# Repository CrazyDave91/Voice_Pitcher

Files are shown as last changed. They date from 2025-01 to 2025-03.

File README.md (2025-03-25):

# Voice Pitcher

This Project implements an Arduino Uno based voice pitcher with mic input and speaker output.

The core parts are listed in the BOM folder. All other parts are things i had lying around:
- BC337-40 NPN Transistor for the speaker driver
- 1N4001 Freewheeling Diode for the speaker driver
- Some random capacitors for filtering the supply and potentiometer output
- Some random jumper cables
- The screws used are M3 maschine screws

# Updates
**20250325**: The pitcher now supports two modes. Default Mode (knob on high pitch at startup), where the knob controls the pitch and Binary Mode (knob on low pitch at startup), where only one octave lower or higher can be selected. The mode is selected at startup depending on the knobs position and seperated by its half point.

# Example Setup
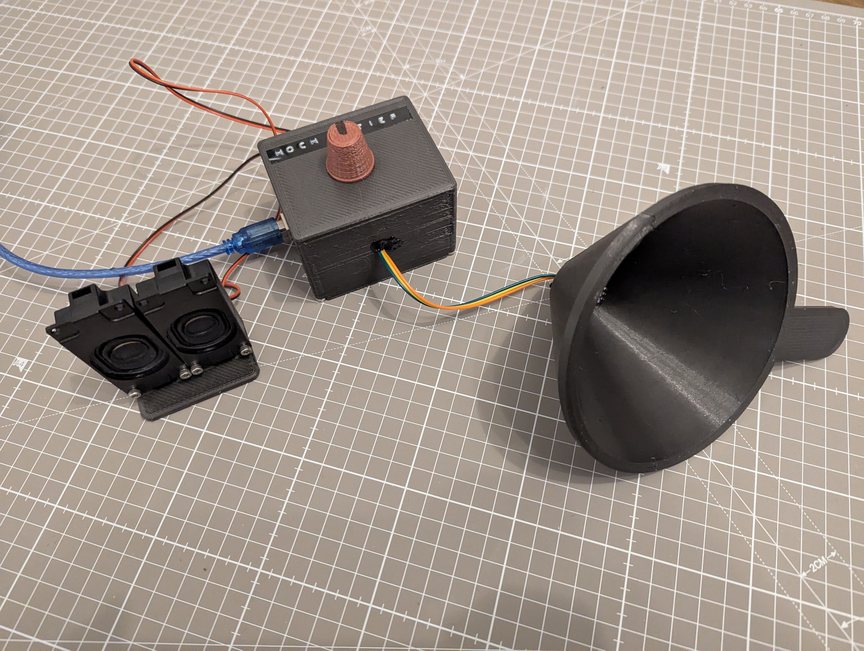
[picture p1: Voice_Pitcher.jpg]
Voice Pitcher Assembly


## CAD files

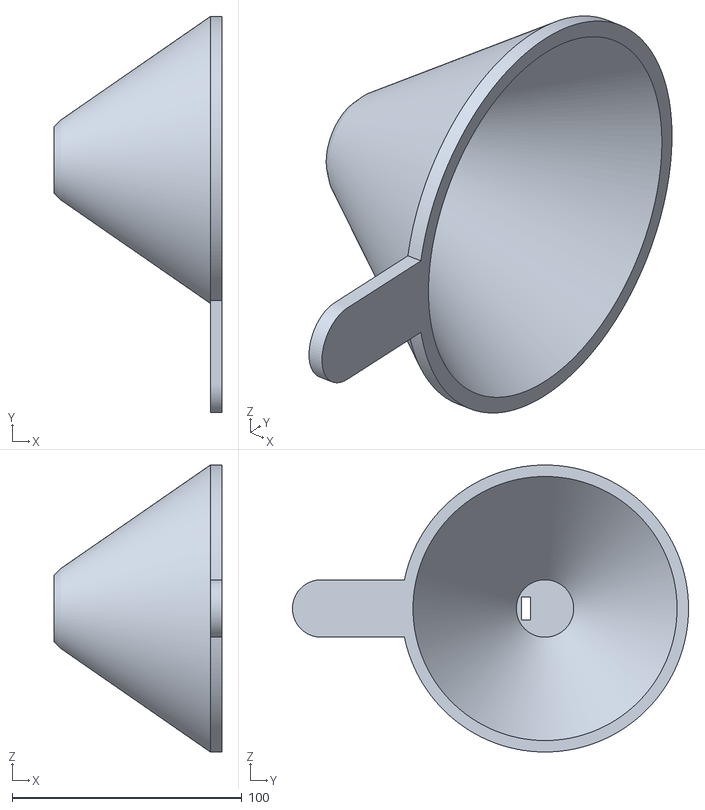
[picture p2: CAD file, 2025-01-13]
Mechanical/VC_Mic.stl
73.0 x 172.5 x 125.0

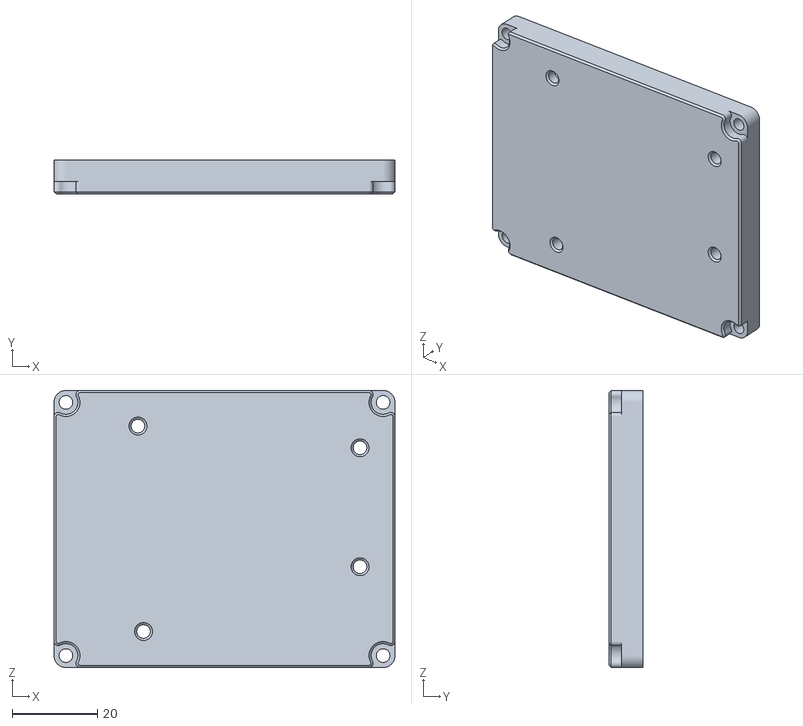
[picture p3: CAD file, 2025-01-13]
Mechanical/VC_Bottom.stl
80.0 x 8.00 x 65.0

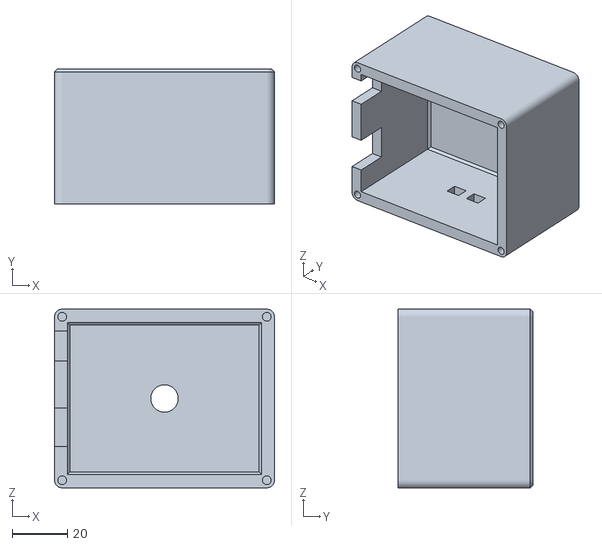
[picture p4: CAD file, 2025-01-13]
Mechanical/VC_Cover.stl
80.0 x 49.0 x 65.0

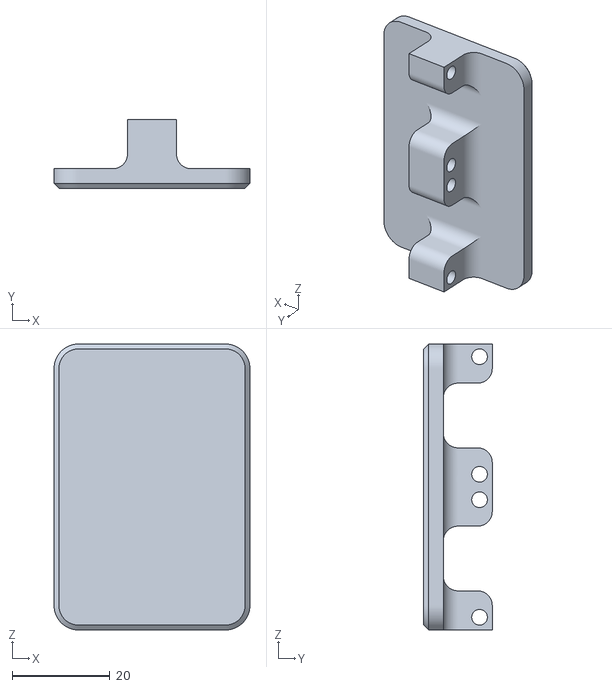
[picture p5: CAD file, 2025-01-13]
Mechanical/VC_Speaker.stl
40.0 x 14.0 x 58.4

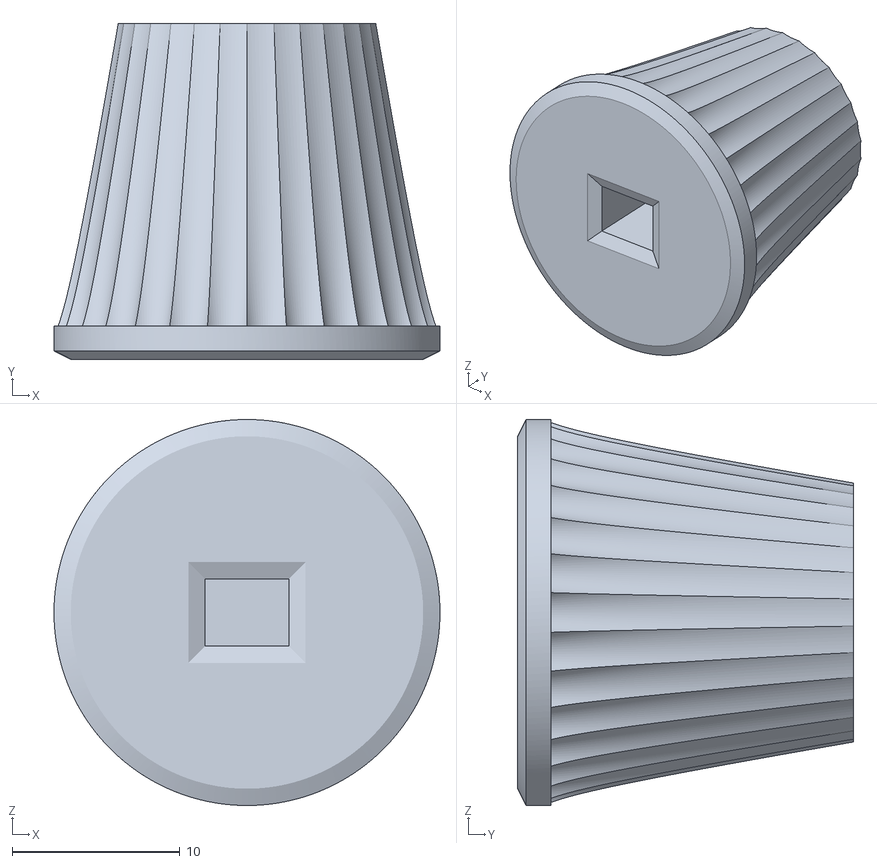
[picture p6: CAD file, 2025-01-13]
Mechanical/VC_Knob.stl
23.0 x 20.0 x 23.0

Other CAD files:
Mechanical/VoiceChanger v12.f3d

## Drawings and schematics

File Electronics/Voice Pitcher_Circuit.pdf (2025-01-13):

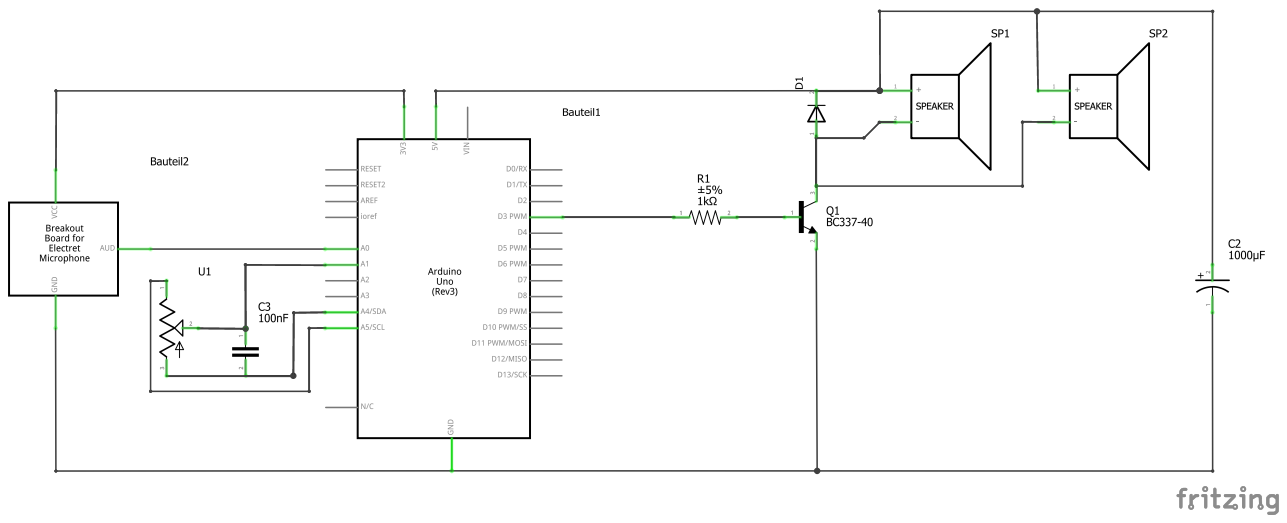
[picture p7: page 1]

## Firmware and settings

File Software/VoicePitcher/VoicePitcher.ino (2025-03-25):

#include <avr/io.h>
#include <avr/interrupt.h>
#define F_CPU 16000000L
#include <util/delay.h>

#define LED 13
#define MICRO A0
#define SPEAKER 3
#define POTI A1
#define POTI_PLUS A4
#define POTI_MINUS A5

#define FILT_400Hz ((uint16_t)(0.11 * 256.0))
#define FILT_4kHz ((uint16_t)(0.65 * 256.0))
#define FILT_8kHz ((uint16_t)(0.80 * 256.0))
#define FILT_DIV ((uint16_t)(256))

#define TIMER_BASE_DIV 13u // Base Frequency = 16Mhz / 64 Pre / DIV = 19,2kHz

#define PITCH_BUFFER_LEN 800

uint8_t sampleBuffer[PITCH_BUFFER_LEN] = {0};
uint16_t inputPointer = 0;
uint16_t outputPointer = 0;
volatile uint8_t outputSample = 128u;
bool continuousPitchMode = true;

/*###############################################
              Initialization
#################################################*/

void setup() {
  initPins();
  initMic();
  initSpeaker();
  initPitchMode();
}

void initPins(void)
{ 
  pinMode(LED, OUTPUT);
  pinMode(SPEAKER, OUTPUT);
  pinMode(MICRO, INPUT);
  pinMode(POTI, INPUT);
  pinMode(POTI_PLUS, OUTPUT);
  pinMode(POTI_MINUS, OUTPUT);
  digitalWrite(POTI_PLUS, HIGH);
  digitalWrite(POTI_MINUS, LOW);
  sei();
}

void initMic(void)
{
  // Init Timer 1 to synch input sampling
  TCCR1A = 0x00;                            // no output & CTC with OCR1A
  TCCR1B = (1<<WGM12)|(1<<CS11)|(1<<CS10);  // CTC with OCR1A & Prescaler 8
  OCR1AH = 0;                               // Frequency = 16Mhz / 64 Pre / OCRA
  OCR1AL = TIMER_BASE_DIV;
  TIMSK1 = (1<<OCIE1A);                     // enable OCRA interrupt
  
  // Init ADC to auto sample
  initAdc0FreeRun();
}

void initAdc0FreeRun(void)
{
  ADCSRA = 0;                                         // Stop ADC and terminate previous conversion
  ADMUX = (1<<REFS0)|(1<<ADLAR);                      // Vref=Vsup & Left Aligned & ADC0 selected
  ADCSRA = (1<<ADEN)|(1<<ADSC)|(1<<ADATE)|(1<<ADPS2); // ADC Enable & Autotrigger & ADC div 16
  ADCSRB = 0;                                         // Free running mode
  DIDR0 = (1<<ADC0D);                                 // Disable digital input buffer of ADC0
}

void initSpeaker(void)
{ 
  // Init Timer 0 to synch output sampling
  TCCR0A = (1<<WGM01);          // no output & CTC with OCR0A 
  TCCR0B = (1<<CS01)|(1<<CS00); // CTC with OCR0A & Prescaler 64
  OCR0A = TIMER_BASE_DIV;       // Frequency = 16Mhz / 64 Pre / OCRA
  TIMSK0 = (1<<OCIE0A);         // enable OCRA interrupt

  // Init Timer 2 for 1bit DAC on pin 3 aka. PD3 connected to OC2B
  TCCR2A = (1<<COM2B1)|(1<<WGM21)|(1<<WGM20); // Fast PWM to Output OC2B set at bottom
  TCCR2B = (1<<CS20);                         // Clock Divider 1
  TIMSK2 = (1<<TOIE2);                        // Timer 2 OVF enable 
}

void initPitchMode(void)
{
  uint8_t poti = readAdcChannel1();
  continuousPitchMode = (poti > 128u);
}

/*###############################################
            Main Loop & Algorithms
#################################################*/

void loop() {
  cli();
  uint8_t poti = readAdcChannel1();
  initAdc0FreeRun();
  setNewSampleRatesForMicAndSpeaker(poti);
  sei();
  _delay_ms(250);
}

uint8_t readAdcChannel1(void)
{
  ADCSRA = 0;                                         // Stop ADC and terminate previous conversion
  ADMUX = (1<<REFS0)|(1<<ADLAR)|(1<<MUX0);            // Vref=Vsup & Left Aligned & ADC1 selected
  ADCSRA = (1<<ADEN)|(1<<ADSC)|(1<<ADPS2)|(1<<ADPS0); // ADC Enable & ADC div 32
  uint8_t running;
  do{
    running = ADCSRA & (1<<ADSC);
  }while(running);
  return ADCH;
}

void setNewSampleRatesForMicAndSpeaker(uint8_t target)
{
  if(target >= 128u)
  {
    OCR0A = TIMER_BASE_DIV;
    if(continuousPitchMode)
    {
      OCR1AL = TIMER_BASE_DIV + ((target - 128u) >> 3u);
    }
    else
    {
      OCR1AL = TIMER_BASE_DIV << 1u;
    }
  }
  else
  {
    if(continuousPitchMode)
    {
      OCR0A = TIMER_BASE_DIV + ((127u - target) >> 3u);
    }
    else
    {
      OCR0A = TIMER_BASE_DIV << 1u;
    }
    OCR1AL = TIMER_BASE_DIV;
  }
}

uint8_t lowPass(uint8_t sample, uint16_t frequency)
{
  static uint8_t last = 128u;
  uint8_t retVal = (uint8_t)(((uint16_t)sample * (uint16_t)frequency + (uint16_t)last * (uint16_t)(FILT_DIV - frequency))/FILT_DIV);
  last = retVal;
  return retVal;
}

/*###############################################
           Interrupt Service Routines
#################################################*/
// Output samples to speaker
ISR(TIMER0_COMPA_vect)
{
  outputSample = lowPass(sampleBuffer[outputPointer], FILT_4kHz);
  outputSample = sampleBuffer[outputPointer];
  outputPointer = (outputPointer + 1u) % PITCH_BUFFER_LEN;
}

// Read Mic at constant sampling rate
ISR(TIMER1_COMPA_vect)
{
  sampleBuffer[inputPointer] = ADCH;
  inputPointer = (inputPointer + 1u) % PITCH_BUFFER_LEN;
}

ISR(TIMER2_OVF_vect)
{
  OCR2B = outputSample;
}

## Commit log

2025-01-13 added bom, fusion files and exports and ardoino sketch
    [VC_Bottom.stl, VC_Cover.stl, VC_Knob.stl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]
2025-01-13 added picture of assembly and updated readme
2025-01-13 added circuit diagram
    [Voice Pitcher.fzz]
2025-03-25 Added second pitch mode for fixed one octave pitch
    [VoicePitcher.ino]
